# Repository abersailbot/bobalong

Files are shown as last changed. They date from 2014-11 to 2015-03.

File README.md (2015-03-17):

Bobalong
=======

This is the working repository of the autonomous sailing boat codenamed Bobalong

## Hardware

Bobalong has the following hardware:
    - HMC6343 Compass
    - EM408 GPS
    - Olimex Leonardo dev board

## Goals

The goals of this project is to take part in Microtransat transatlantic race (http://www.microtransat.org/) with the aim of creating a autonomous sailing boat capable of sailing across the Atlantic Ocean.

## Features

- Waypoint following
- GSM Comms(TODO)
- Sat Comms(TODO)
- Low power software design (TODO)

## BIG TODO ##

* Look at data logging
    - Provide support for different devices
* Force control system into ino file
    - code should provide support for that ino file

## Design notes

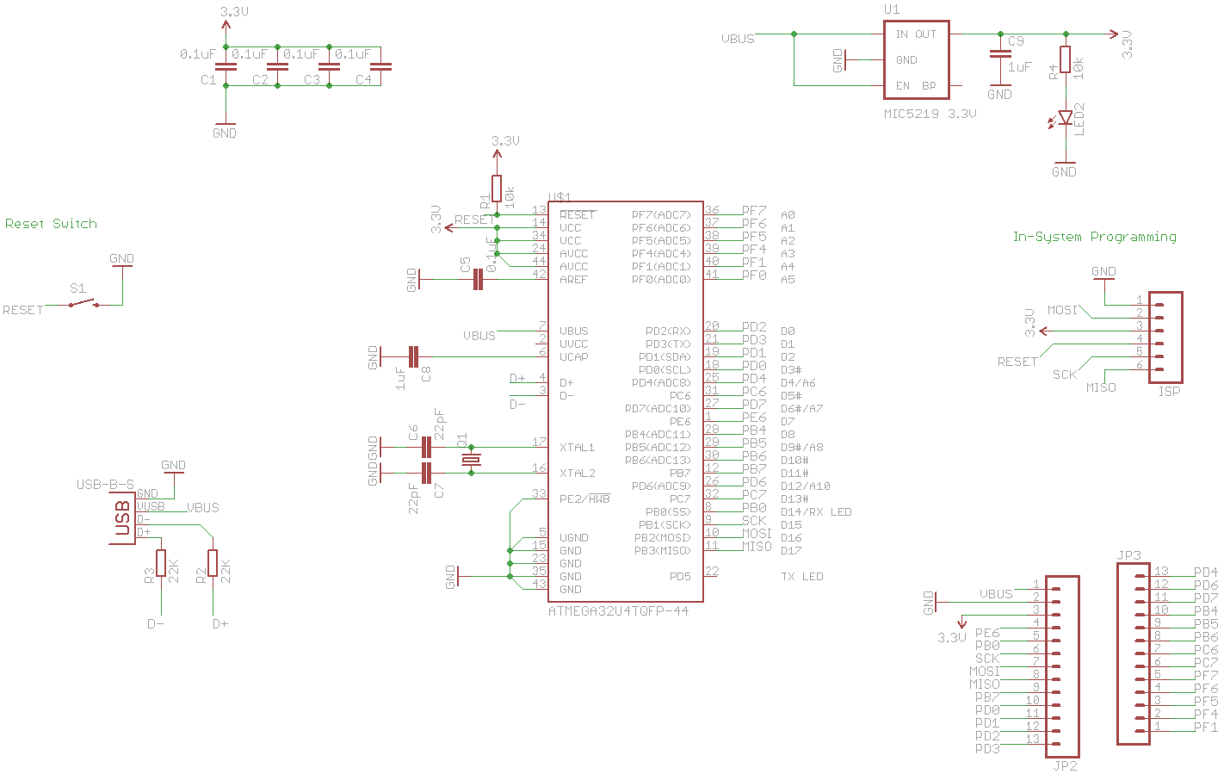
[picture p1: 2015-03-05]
pcb/motherboard.png

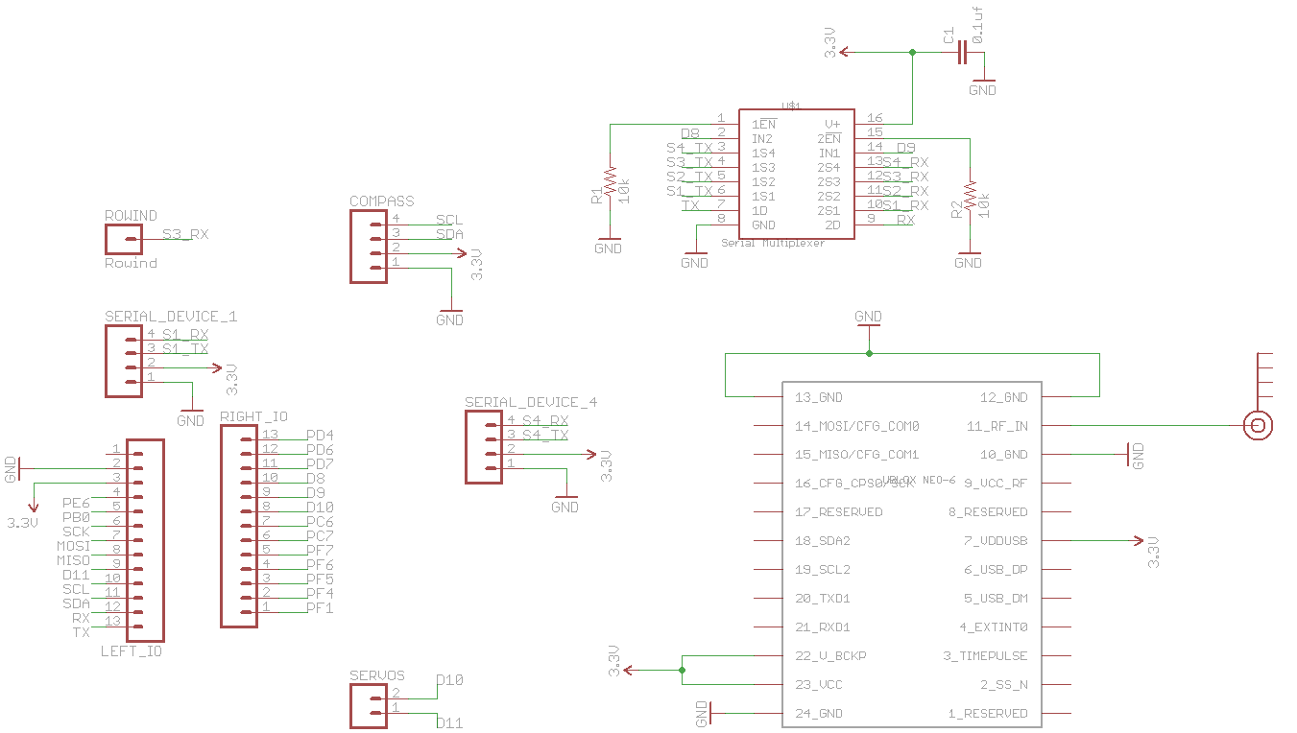
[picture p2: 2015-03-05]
pcb/sensorboard.png

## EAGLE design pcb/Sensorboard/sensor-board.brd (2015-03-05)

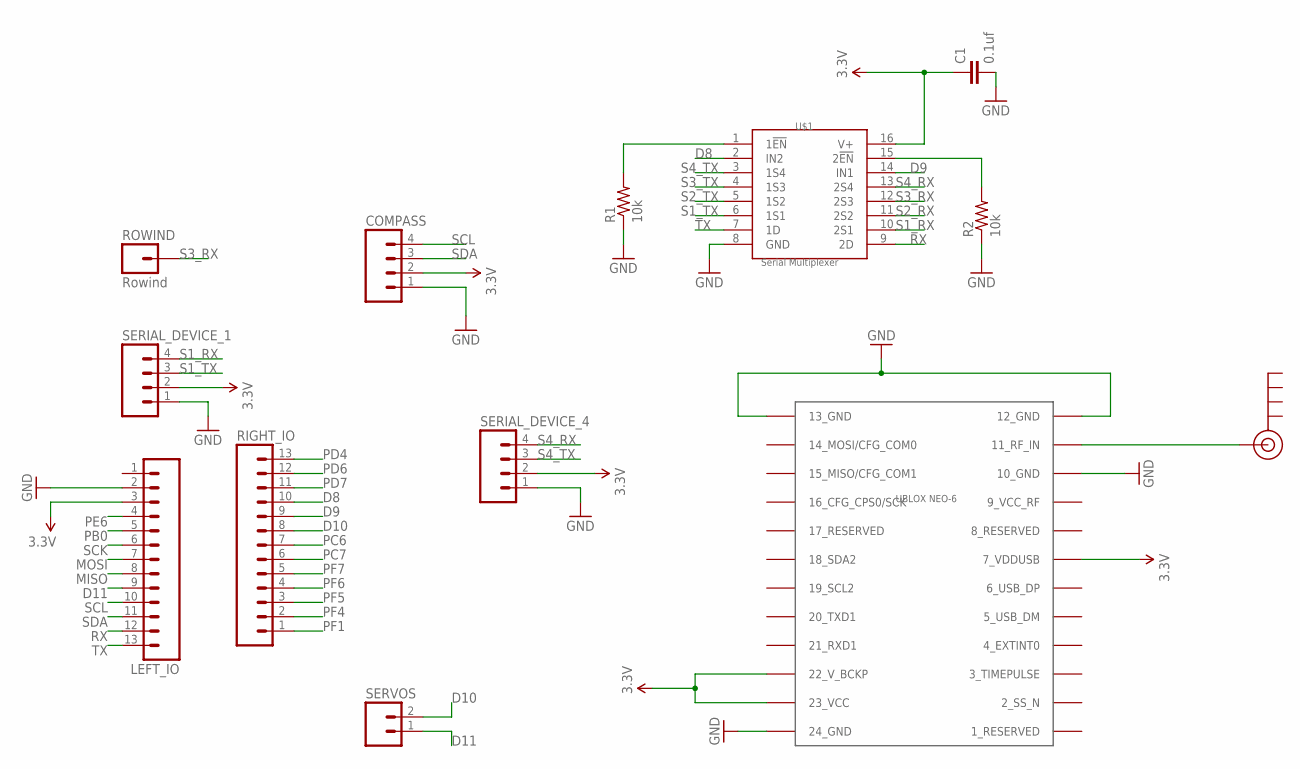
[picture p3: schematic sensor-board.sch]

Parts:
C1: 0.1uf; C0805
COMPASS: M04PTH; 1X04
J$1: SMA_EDGE; SMA-EDGE
LEFT_IO: M13; 1X13
R1, R2: 10k; AXIAL-0.3
RIGHT_IO: M13; 1X13
ROWIND: Rowind; 1X01
SERIAL_DEVICE_1, SERIAL_DEVICE_4: M04PTH; 1X04
SERVOS: M02PTH; 1X02
U$1: Serial Multiplexer; 16TSSOP
U$2: UBLOX_NEO-6; UBLOX_NEO-6P

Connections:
3.3V: C1.1, COMPASS.2, LEFT_IO.3, SERIAL_DEVICE_1.2, SERIAL_DEVICE_4.2, U$1.16 (V+), U$2.7_VDDUSB, U$2.22_V_BCKP, U$2.23_VCC
D8: RIGHT_IO.10, U$1.2 (IN2)
D9: RIGHT_IO.9, U$1.14 (IN1)
D10: RIGHT_IO.8, SERVOS.2
D11: LEFT_IO.9, SERVOS.1
GND: C1.2, COMPASS.1, LEFT_IO.2, R1.P$1 (1), R2.P$1 (1), SERIAL_DEVICE_1.1, SERIAL_DEVICE_4.1, U$1.8 (GND), U$2.10_GND, U$2.12_GND, U$2.13_GND, U$2.24_GND
MISO: LEFT_IO.8
MOSI: LEFT_IO.7
unnamed: R1.P$2 (2), U$1.1 (1!EN)
unnamed: R2.P$2 (2), U$1.15 (2!EN)
unnamed: J$1.SIG (SIGNAL), U$2.11_RF_IN
PB0: LEFT_IO.5
PC6: RIGHT_IO.7
PC7: RIGHT_IO.6
PD4: RIGHT_IO.13
PD6: RIGHT_IO.12
PD7: RIGHT_IO.11
PE6: LEFT_IO.4
PF1: RIGHT_IO.1
PF4: RIGHT_IO.2
PF5: RIGHT_IO.3
PF6: RIGHT_IO.4
PF7: RIGHT_IO.5
RX: LEFT_IO.12, U$1.9 (2D)
S1_RX: SERIAL_DEVICE_1.4, U$1.10 (2S1)
S1_TX: SERIAL_DEVICE_1.3, U$1.6 (1S1)
S2_RX: U$1.11 (2S2)
S2_TX: U$1.5 (1S2)
S3_RX: ROWIND.1, U$1.12 (2S3)
S3_TX: U$1.4 (1S3)
S4_RX: SERIAL_DEVICE_4.4, U$1.13 (2S4)
S4_TX: SERIAL_DEVICE_4.3, U$1.3 (1S4)
SCK: LEFT_IO.6
SCL: COMPASS.4, LEFT_IO.10
SDA: COMPASS.3, LEFT_IO.11
TX: LEFT_IO.13, U$1.7 (1D)

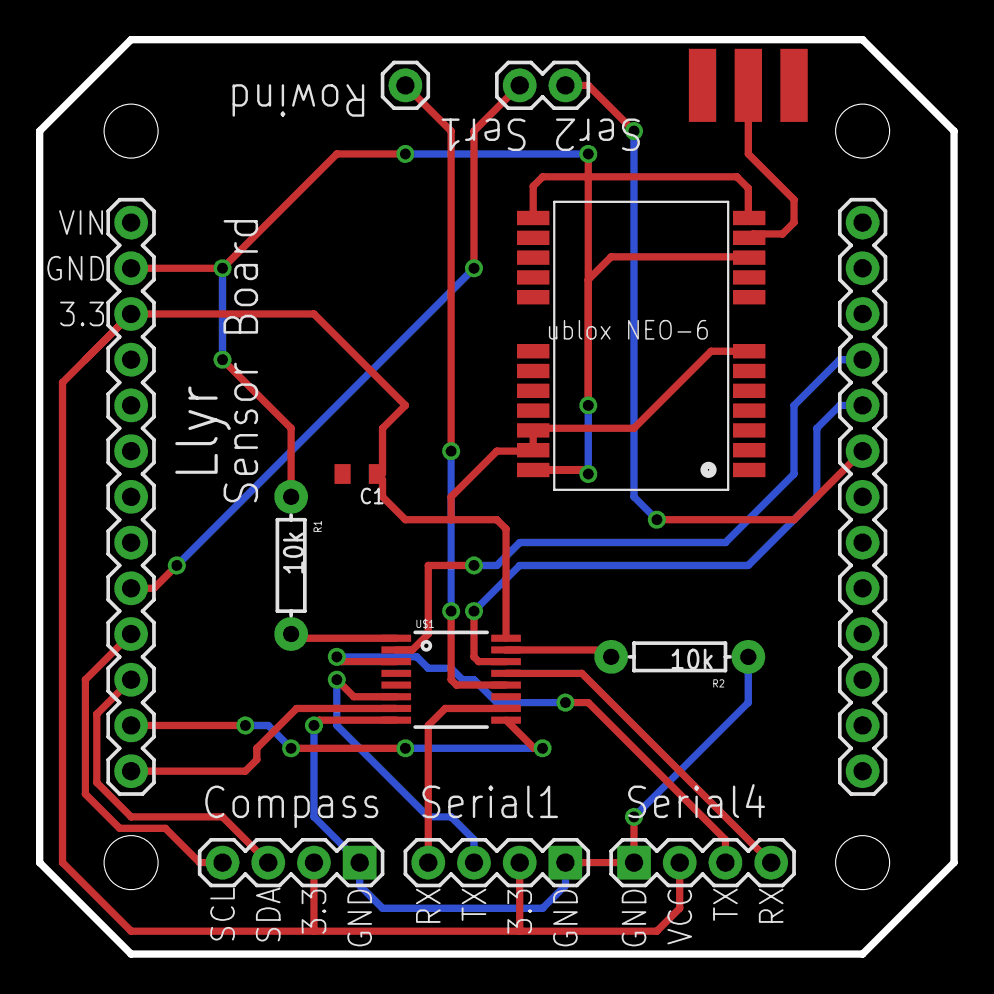
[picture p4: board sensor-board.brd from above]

Board: 2 copper layers, 50.8 x 50.8 mm, 13 parts (0 on the bottom side), 18 nets.

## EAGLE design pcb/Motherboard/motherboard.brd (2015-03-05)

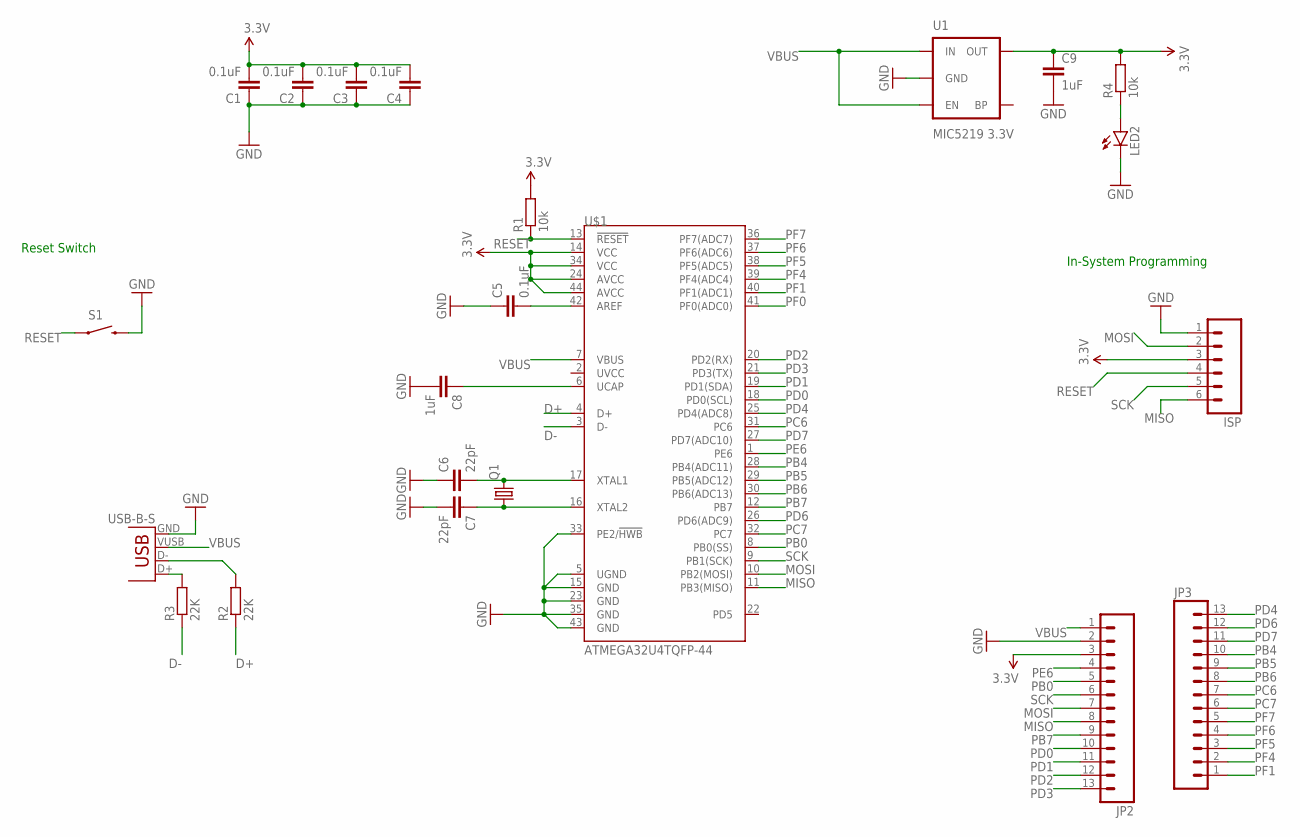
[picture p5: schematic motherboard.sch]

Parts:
C1, C2, C3, C4, C5: 0.1uF; C0805
C6, C7: 22pF; C0805
C8, C9: 1uF; C0805
ISP: M06SMD; 1X06-SMD
JP1: USB-B-S; USB-B-SMT
JP2, JP3: M13; 1X13
LED2: LED1206; LED-1206
Q1: CRYSTALHC49S; HC49/S
R1, R4: 10k; R0805
R2, R3: 22K; R0805
S1: SWITCH-MOMENTARY-2PTH; TACTILE-PTH
U1: MIC5219 3.3V; SOT23-5
U$1: ATMEGA32U4TQFP-44; TQFP44

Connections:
3.3V: C1.2, C2.2, C3.2, C4.2, C9.1, ISP.3, JP2.3, R1.2, R4.2, U1.5 (OUT), U$1.14 (VCC), U$1.24 (AVCC), U$1.34 (VCC), U$1.44 (AVCC)
D+: R2.1, U$1.4 (D+)
D-: R3.1, U$1.3 (D-)
GND: C1.1, C2.1, C3.1, C4.1, C5.1, C6.1, C7.2, C8.2, C9.2, ISP.1, JP1.GND, JP2.2, LED2.C, S1.3 (2), U1.2 (GND), U$1.5 (UGND), U$1.15 (GND), U$1.23 (GND), U$1.33 (PE2/!HWB), U$1.35 (GND), U$1.43 (GND)
MISO: ISP.6, JP2.8, U$1.11 (PB3(MISO))
MOSI: ISP.2, JP2.7, U$1.10 (PB2(MOSI))
unnamed: C7.1, Q1.1, U$1.16 (XTAL2)
unnamed: C5.2, U$1.42 (AREF)
unnamed: C6.2, Q1.2, U$1.17 (XTAL1)
unnamed: JP1.D+, R3.2
unnamed: JP1.D-, R2.2
unnamed: LED2.A, R4.1
unnamed: C8.1, U$1.6 (UCAP)
PB0: JP2.5, U$1.8 (PB0(SS))
PB4: JP3.10, U$1.28 (PB4(ADC11))
PB5: JP3.9, U$1.29 (PB5(ADC12))
PB6: JP3.8, U$1.30 (PB6(ADC13))
PB7: JP2.9, U$1.12 (PB7)
PC6: JP3.7, U$1.31 (PC6)
PC7: JP3.6, U$1.32 (PC7)
PD0: JP2.10, U$1.18 (PD0(SCL))
PD1: JP2.11, U$1.19 (PD1(SDA))
PD2: JP2.12, U$1.20 (PD2(RX))
PD3: JP2.13, U$1.21 (PD3(TX))
PD4: JP3.13, U$1.25 (PD4(ADC8))
PD6: JP3.12, U$1.26 (PD6(ADC9))
PD7: JP3.11, U$1.27 (PD7(ADC10))
PE6: JP2.4, U$1.1 (PE6)
PF0: U$1.41 (PF0(ADC0))
PF1: JP3.1, U$1.40 (PF1(ADC1))
PF4: JP3.2, U$1.39 (PF4(ADC4))
PF5: JP3.3, U$1.38 (PF5(ADC5))
PF6: JP3.4, U$1.37 (PF6(ADC6))
PF7: JP3.5, U$1.36 (PF7(ADC7))
RESET: ISP.4, R1.1, S1.1, U$1.13 (!RESET)
SCK: ISP.5, JP2.6, U$1.9 (PB1(SCK))
VBUS: JP1.VUSB (VBUS), JP2.1, U1.1 (IN), U1.3 (EN), U$1.7 (VBUS)

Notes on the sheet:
In-System Programming
Reset Switch

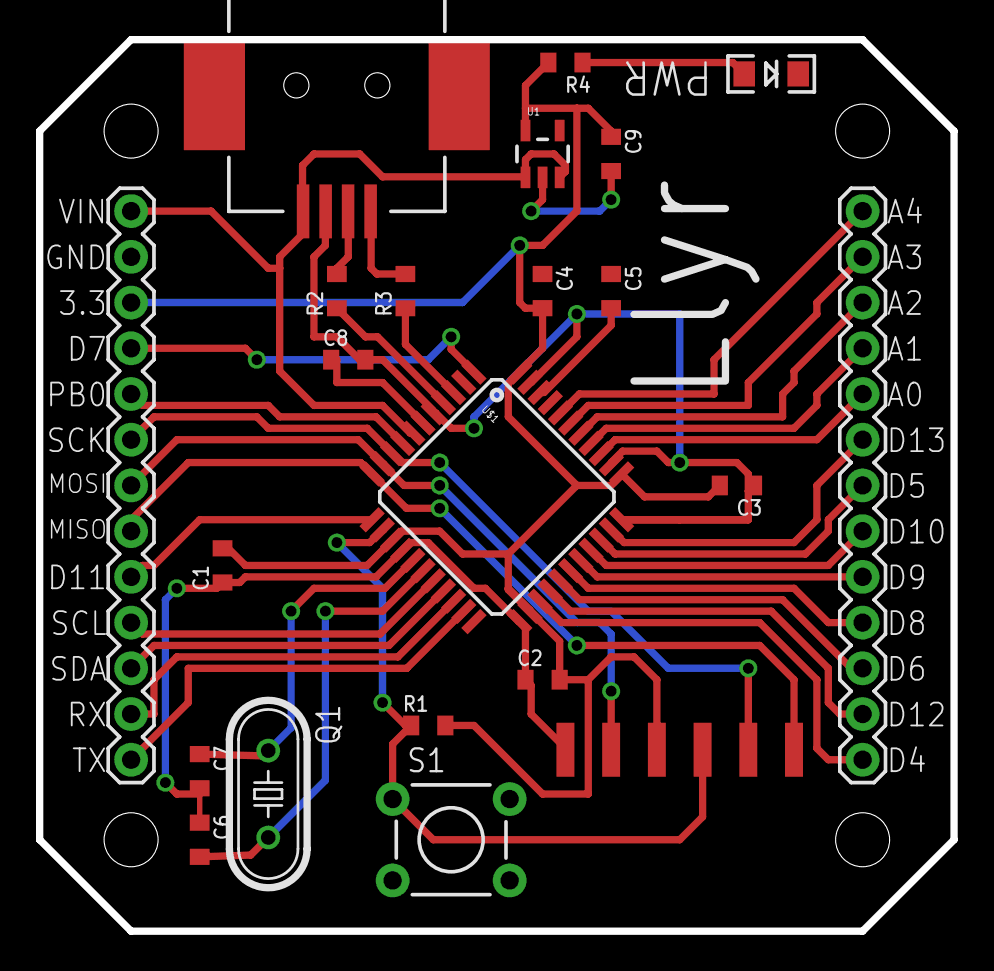
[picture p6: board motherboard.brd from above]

Board: 2 copper layers, 50.8 x 49.5 mm, 22 parts (0 on the bottom side), 36 nets.

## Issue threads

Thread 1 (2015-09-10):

Tidy up electronics and find a better box

thip, 2015-09-10:
Main electronics (Arduino, Data logger, GSM modem etc) should be stuck down to a board with hot glue or screwed on so that layout and wires can be kept tidy.

A new box will be needed to make space for this. Think about how much of a pain it is to open and close... look at the current box for a horrible example and look at kitty/dewi's boxes for a nice example

Closed 2015-10-22.

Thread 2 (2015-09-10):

Assemble solar power system

thip, 2015-09-10:
Almost everything needed should be in a bag in the DSL.

The panels will charge the batteries directly, (each panel needs a diode to protect it from reverse current if it ends up in the shade... try and find one with minimal forward drop and sufficiently high breakdown voltage)

Use the adjustable reg to drop the output from the battery to 5v for the main electronics  and the boost converter to  jump it up to 12v for the rowind

Danyc0, 2015-11-19:
Why use an adjustable reg? It's going down to 5V, a standard 5V switch mode buck is way more effecient in both space and power. Unless there's some other need for it to be adjustable?

thip, 2015-11-19:
Because it's what I had on hand and it's convenient from a prototyping perspective

thip, 2015-11-19:
And it is a buck reg, I'd be surprised if a standard  one is significantly more efficient

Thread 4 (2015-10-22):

Identify Hardware (Critical)

JSpringett, 2015-10-22:
New hardware needs to be identified and selected for Bobalong, this task should not take long at all. The following hardware needs to found and acquired:
* Microcontroller
* Compass
* GPS

Previously we used an Olimexino-32U4, this board is relatively cheap (Around $12.95), more importantly it uses low power components and had 2 serial ports(GPS and the ROWIND both use serial). Arduino's software serial is the devil!! Stay away from it!!!!!!!!!!!

We originally had a HMC6343 compass, this compass is great, low power and accurate. However it is expensive, though Dan has apparently found a cheap source, so nag him!

We used a Em408 GPS, they are quite nice.

colinsauze, 2015-11-18:
The 32u4 doesn't have 2 serial ports. It has one USB port which can emulate a USB to serial converter and a standard hardware UART. The USB port is only good for connecting to a PC (not to peripherals like GPS and Rowind), but it can do strange things to the behaviour of the device if power comes in over USB. If you want lots of real hardware UARTs use multiple 32u4s or get a Teensy.

naturesyouth, 2015-11-25:
gps give good looking nema strings over serial at 9600, although looking to move to a Maestro A2200-A ( http://uk.rs-online.com/web/p/gps-modules/7658968/ )

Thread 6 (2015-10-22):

GPS Driver

JSpringett, 2015-10-22:
A GPS driver already exists that couples with TinyGPS(A awesome library). This driver is however deeply coupled with Arduino so if a new platform is chosen then this will need some rework.

colinsauze, 2015-11-18:
Just had a look through TinyGPS code and nothing is Arduino specific. You have to read the serial port in your own code.

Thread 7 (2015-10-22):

Rowind Driver

JSpringett, 2015-10-22:
A functioning Rowind driver already exists, however it is deeply coupled with Arduino (Arduino serial) and so if a different platform is chosen then this will need to be rewritten.

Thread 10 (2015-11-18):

design electronics, inculding pcb for mounting

naturesyouth, 2015-11-18:

thip, 2015-11-18:
Design, breadboard and *test* the whole system first before you think about moving to a PCB if you are going to do one.

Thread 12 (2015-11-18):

Fix joint between sail counterweight and wing.

colinsauze, 2015-11-18:
The carbon fibre linking the counterweight and the wing has snapped. It needs replacing with something much stronger.

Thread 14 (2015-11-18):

Install satellite comms modem

colinsauze, 2015-11-18:
A Rockblock (Iridium 9602, see http://www.rock7mobile.com/products-rockblock) is probably the best thing to use. There might be one of these spare in the department, look in Mark Neal's storeroom/extra office. This will need to be connected to a serial port on the Arduino, software serial may have issues. The rockblock needs a 5V power supply, but uses 3.3V I/O.

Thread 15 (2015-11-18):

Write satellite comms software

colinsauze, 2015-11-18:
Write software to send telemetry data back over Iridium. There is a good library available from http://arduiniana.org/libraries/iridiumsbd/. Note that transmitting may take several seconds and cannot happen more than once every few minutes as the capacitor on the rockblock needs to recharge.

A fancy, but only semi-tested data bucketing system designed to produce summary data was written for Morwyn, code available from https://github.com/colinsauze/morwyn/blob/master/comms/src/comms.ino. The idea of this is to produce a summary of what happened over the last few minutes, so telemetry packets aren't just snapshots of what is currently going on. Its really hard to tell if the boat is pointing the wrong way just at this instant in time or if its been doing it for the whole time since the last message.

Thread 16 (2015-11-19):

Complete main control loop

colinsauze, 2015-11-19:
The current control system code (control-system/src/control-system.ino) may not work correctly. I suspect gains for the PI controller are not fully tuned. The loop's frequency is not controlled, its probably best to limit it to around 10hz. There is no need to read the GPS every time round the loop, once every 10 seconds should be more than enough.

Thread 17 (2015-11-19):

Label all wires

colinsauze, 2015-11-19:
Make sure every wire has a label attached to it. All power supply wires should indicate the voltage they are using.

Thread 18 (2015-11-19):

Remove spade connectors

colinsauze, 2015-11-19:
All spade connectors should be replaced with connectors that cannot get their polarity mixed up (e.g. deans connectors). Far too many pieces of hardware made the ultimate sacrifice learning this lesson.

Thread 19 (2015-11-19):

Check polarity on deans connectors

colinsauze, 2015-11-19:
Check the polarity is correct on all deans connectors. A number of connectors were found to be wired backwards on Dewi. There are positive and negative symbols on the connectors. DO THIS BEFORE POWERING ON ANYTHING!!!!

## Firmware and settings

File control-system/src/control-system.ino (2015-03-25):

#include <Wire.h>
#include <Servo.h>
#include "utils.h"
#include "sensors.h"
#include "hardware.h"
#include "waypoint_mgr.h"
#include "sd_logger.hpp"
#include "boat_state.hpp"

#define SAIL_LEFT	135
#define SAIL_RIGHT	45

int desired_heading;
SDLogger sdLogger;

BoatState lastState;

void setup() {
	delay(5000);
	Serial.begin(9600);
	Serial1.begin(4800);
	Serial.println("Starting up");

	pinMode(MULTIPLEXER_D1_PIN, OUTPUT);
	pinMode(MULTIPLEXER_D2_PIN, OUTPUT);

	digitalWrite(MULTIPLEXER_D1_PIN, LOW);
	digitalWrite(MULTIPLEXER_D2_PIN, LOW);

	Sensors.initialise(SENSOR_COMPASS | SENSOR_GPS | SENSOR_ROWIND);

	initialise_servos();

	Waypoints.add_waypoint(52.400246, -3.869921);
	Waypoints.add_waypoint(52.400825, -3.870545);
	Waypoints.add_waypoint(52.400816, -3.869552);
	Waypoints.add_waypoint(52.399860, -3.869579);

	Serial.println("Initialised");
}


////////////////////////////////////////////////////////////////////////////////
void loop() {
	static int rudder_pos = 90;

	Sensors.read();

	// log sensor data
	startLog();
	log_compass();
	log_gps();
	log_wind();
	endLog();

	// log to the sd card
	sdLogger.appendLog();

	// advance to the next waypoint if we are there
	if(at_waypoint()) {
		Waypoints.advance();
	}

	desired_heading = clamp_angle(desiredHeading());
	Serial.print("Desired: "); Serial.println(desired_heading);

	// set rudder
	rudder_pos = get_rudder_angle(Sensors.bearing());
	Serial.print("Rudder pos: "); Serial.println(rudder_pos);
	set_servo(SERVO_RUDDER, rudder_pos);

	setSail();
}

////////////////////////////////////////////////////////////////////////////////
bool at_waypoint()
{
	GPSPosition curr_pos = Sensors.position();
	GPSPosition wp = Waypoints.current();

	float dist = TinyGPS::distance_between(curr_pos.latitude, curr_pos.longitude, wp.latitude, wp.longitude);

	if( dist < 10) {
		Serial.println("Hit Waypoint");
		return true;
	} else {
		return false;
	}
}

////////////////////////////////////////////////////////////////////////////////
int desiredHeading()
{
	GPSPosition curr_pos = Sensors.position();
	GPSPosition wp = Waypoints.current();

	return TinyGPS::course_to(curr_pos.latitude, curr_pos.longitude, wp.latitude, wp.longitude);
}

//////////////////////////////////////////////////////////////////////////
int get_rudder_angle(int heading)
{

	// PI Controller
	float pCorrection;
	float iCorrection;
	float error;
	static float errorSum;
	int rudderAngle;


	// The desired heading is now relative to zero
	float desired_headingCP = desired_heading - heading;

	// Finding out if the value should be negative or positive and how big
	if (desired_headingCP > 180){
		desired_headingCP -= 360;
	}
	else if (desired_headingCP < -180){
		desired_headingCP += 360;
	}


	// A positive number means that the boat will turn left.
	// A negative number is right

	//  P
	error = desired_headingCP * (-1);
	pCorrection = P_VAL * error;
	lastState.pGain = pCorrection;


	//  I
	errorSum += error;
	iCorrection = I_VAL * errorSum;
	lastState.iGain = iCorrection;
	lastState.errorSum = errorSum;

	errorSum *= 0.95;

	rudderAngle = NORMAL_RUDDER_POS + round(pCorrection + iCorrection);

	// Making sure the rudder does not go over 45 degrees from normal position (90 deg(?))
	if (rudderAngle > (NORMAL_RUDDER_POS + 45)){
		rudderAngle = NORMAL_RUDDER_POS + 45;
	}
	else if (rudderAngle < (NORMAL_RUDDER_POS - 45)){
		rudderAngle = NORMAL_RUDDER_POS - 45;
	}

	return rudderAngle;
}

////////////////////////////////////////////////////////////////////////////////
void setSail()
{
	if(Sensors.wind_direction() > 180) {
		set_servo(SERVO_SAIL, SAIL_LEFT);
	} else {
		set_servo(SERVO_SAIL, SAIL_RIGHT);
	}
}


////////////////////////////////////////////////////////////////////////////////
// Logging to the serial monitor
//
////////////////////////////////////////////////////////////////////////////////

////////////////////////////////////////////////////////////////////////////////
void log_compass() {
	Serial.print(" Heading: ");
	Serial.print(Sensors.bearing());
	Serial.print(" Pitch: ");
	Serial.print(Sensors.pitch());
	Serial.print(" Roll: ");
	Serial.print(Sensors.roll());
}

////////////////////////////////////////////////////////////////////////////////
void log_gps() {
	GPSPosition pos = Sensors.position();
	Serial.print(" Latitude: "); Serial.print(pos.latitude, 6); Serial.print(" Longitude: "); Serial.print(pos.longitude, 6);

	GPSPosition wp = Waypoints.current();
	float dist = TinyGPS::distance_between(wp.latitude, wp.longitude, pos.latitude, pos.longitude);

	Serial.print(" WpDistance: "); Serial.print(dist);
	Serial.print(" Waypoint: "); Serial.print(Waypoints.current_index());
}

////////////////////////////////////////////////////////////////////////////////
void log_wind() {
	Serial.print(" WindSpd: "); Serial.print(Sensors.wind_speed()); Serial.print(" WindDir: "); Serial.print(Sensors.wind_direction());
}

////////////////////////////////////////////////////////////////////////////////
void startLog()
{
	set_multiplexer(MULTIPLEXER_SERIAL1);

	GPSDateTime time = Sensors.date_time();

	// timestamp
	Serial.print(time.day); Serial.print("/");
	Serial.print(time.month); Serial.print("/");
	Serial.println(time.year);

	Serial.print(time.hour); Serial.print(":");
	Serial.print(time.minute); Serial.print(":");
	Serial.print(time.second); Serial.print(" ");

}

////////////////////////////////////////////////////////////////////////////////
void endLog()
{
	Serial.println();
}

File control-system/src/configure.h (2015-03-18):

/*
	configure.h

	Contains all the configuration for Bobalong, such as pin setting,
	and debug level.

	This code is released under the terms of the LGPLv3 licence.
 */

#include "utils.h"

#ifndef CONFIGURE_H
#define CONFIGURE_H

// The current debug level of the boat
#define DEBUG_LEVEL 			DEBUG_LEVEL_MINOR

#define TEST_SENSORS

/// ///////////////////////////////////////////////////////////////////////
///
/// Pin Definitions
///
//////////////////////////////////////////////////////////////////////////


#define PIN_GPS_ENABLE	   		4  	// the enable must be high for the GPS to work,
                              		// if its low then the gps is in sleep
                              		// mode(Double check this).
// multiplexer
#define MULTIPLEXER_D1_PIN		9
#define MULTIPLEXER_D2_PIN		8
#define MULTIPLEXER_SERIAL1		1
#define MULTIPLEXER_GPS			2
#define MULTIPLEXER_ROWIND		4

// Servo
#define PIN_RUDDER_DATA	   	11
#define PIN_SAIL_DATA	   	10

// PI Controller
#define P_VAL				1.00
#define I_VAL				0.01
#define NORMAL_RUDDER_POS	90

#endif

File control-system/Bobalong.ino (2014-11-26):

// Arduino Libraries

/////////////////////////////////////////////////////////////////
#define TEST_COMPASS


/////////////////////////////////////////////////////////////////
// Boat libraries
#include "pin_defs.h"

#ifdef TEST_COMPASS
	#include "compass.h"
#endif#

#ifdef TEST_ROWIND
	#include "wind_sensor.h"
#endif

#ifdef TEST_GPS
	#include "gps.h"
#endif

void setup() {
	Serial.begin(9600);
	Serial.println("Starting up");
	
#ifdef TEST_COMPASS
	Compass.initialise();
#endif

#ifdef TEST_GPS
	
#endif

#ifdef TEST_ROWIND
#endif
}


void compass_test() {
#ifdef TEST_COMPASS
	Serial.println("Reading compass");
	Compass.poll_data();
	Serial.print("Heading: ");
	Serial.println(Compass.bearing());	
#endif
}

void gps_test() {
	
}

void loop() {
	compass_test();
}

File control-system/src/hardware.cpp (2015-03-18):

/*
    hardware.h

    Contains m functions for interacting with simple hardware on the boat,
    this includes:
    - Rudder Servo
    - Sail Servo
    - Serial multiplexer

    This code is released under the terms of the LGPLv3 licence.
*/

#include "hardware.h"
#include "Servo.h"
#include "configure.h"

Servo rudder_servo;
Servo sail_servo;

////////////////////////////////////////////////////////////////////////////////
void initialise_servos()
{
    rudder_servo.attach(PIN_RUDDER_DATA);
    sail_servo.attach(PIN_SAIL_DATA);
}

////////////////////////////////////////////////////////////////////////////////
void set_multiplexer(uint8_t line)
{
    if(line & 1) {
        Serial.println("Serial changed to Serial 1");
        digitalWrite(MULTIPLEXER_D1_PIN, LOW);
        digitalWrite(MULTIPLEXER_D2_PIN, LOW);
    } else if(line & 2) {
        Serial.println("Serial changed to GPS");
        digitalWrite(MULTIPLEXER_D1_PIN, HIGH);
        digitalWrite(MULTIPLEXER_D2_PIN, LOW);
    } else if(line & 4){
        Serial.println("Serial changed to rowind");
        digitalWrite(MULTIPLEXER_D1_PIN, LOW);
        digitalWrite(MULTIPLEXER_D2_PIN, HIGH);
    } else {
        Serial.println("Serial changed to Serial 4");
        digitalWrite(MULTIPLEXER_D1_PIN, HIGH);
        digitalWrite(MULTIPLEXER_D2_PIN, HIGH);
    }
    delay(50);
}

//////////////////////////////////////////////////////////////////////////
void set_servo(uint8_t servo, uint8_t angle)
{
    if(servo == SERVO_SAIL) {
        sail_servo.write(angle);
    } else {
        rudder_servo.write(angle);
    }
}

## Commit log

2014-10-19 -Fixed typo in compass -Refactored GPS to be an object
    [compass.cpp, gps.cpp]
2014-11-27 Fixed a ton of typos
    [compass.cpp, configure.h, gps.cpp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]
2014-12-06 Made some values in the pid controller static so they don't reset on each call. Could do with moving the PI coeficients into config.h as defines
2014-12-09 starte testing gps, we have some odd issues with it not updating.
    [compass.cpp, configure.h, control-system.ino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]
2014-12-11 -Tested rowind -tested pid, now working correctly
    [compass.cpp, configure.h, control-system.ino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]
2014-12-13 - implemented some simple sailing logic - PID changes, not working correctly
    [compass.cpp, configure.h, control-system.ino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]
2015-02-22 Added pcb
    [motherboard.brd, motherboard.sch]
2015-02-24 - Updated PCB to include bigger components, 805 instead of 804 - Improved PCB layout
    [motherboard.brd, motherboard.sch]
2015-03-05 Added sensor board and reorganized
    [motherboard.brd, motherboard.sch, sensor-board.brd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]
2015-03-13 Code wouldn't upload because I had not set the upload board model
2015-03-17 Made a couple changes and fixed some stuff
    [control-system.ino, gps.cpp, hardware.cpp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]
2015-03-18 Fixed a bunch of bugs and created better logging code
    [compass.cpp, configure.h, control-system.ino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]
2015-03-18 Applied a fix to getting the time from the GPS, needs testing
    [control-system.ino, gps.cpp]
2015-03-23 Fixed some compass issues
    [control-system.ino, gps.cpp, sensors.cpp]
2015-03-24 Removed temp rudder setting function
2015-03-25 Implemented a boat state struct and added pid data logging
2015-04-03 number of changes and little fixes after a car park and sail
    [control-system.ino, gps.cpp, sensors.cpp]

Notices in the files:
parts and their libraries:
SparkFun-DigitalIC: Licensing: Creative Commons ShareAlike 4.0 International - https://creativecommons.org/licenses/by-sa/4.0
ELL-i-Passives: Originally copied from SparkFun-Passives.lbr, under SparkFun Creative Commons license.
